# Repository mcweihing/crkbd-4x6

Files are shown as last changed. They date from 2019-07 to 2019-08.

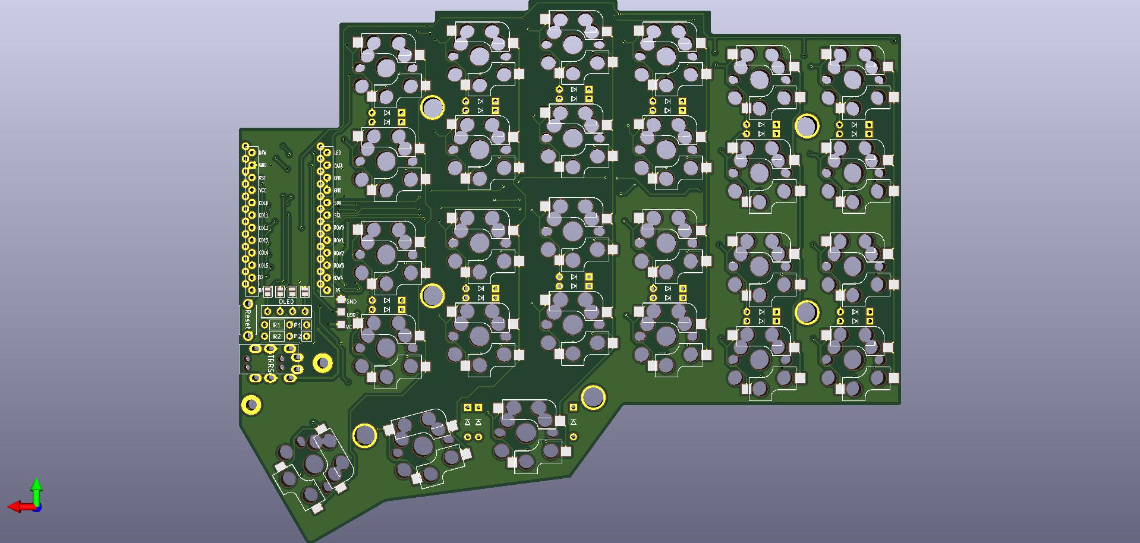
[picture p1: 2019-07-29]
pictures/back.jpg

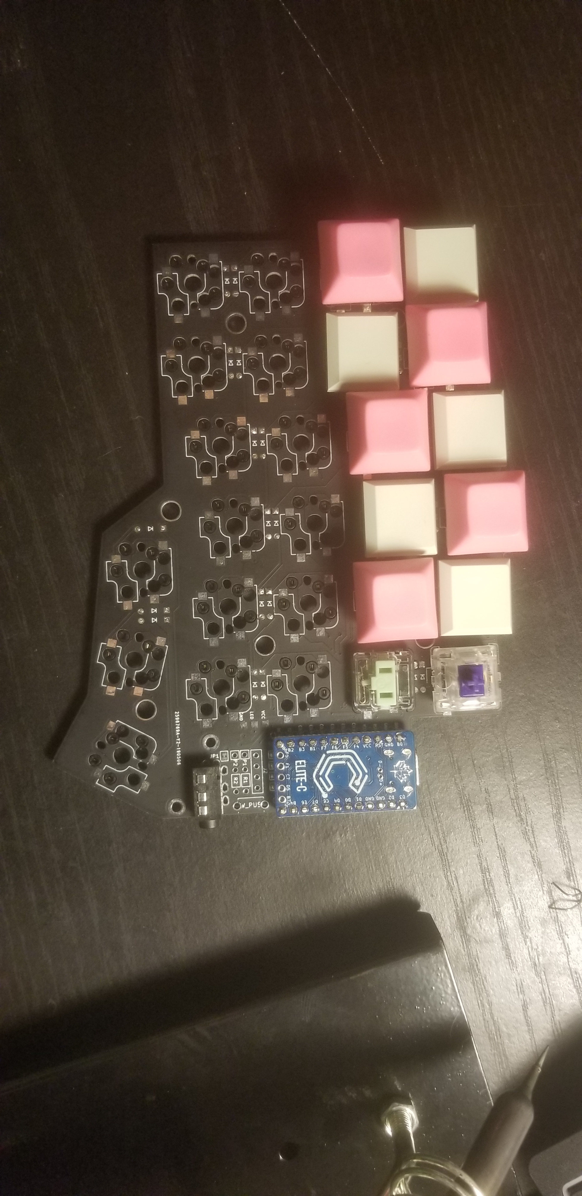
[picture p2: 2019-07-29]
pictures/20190529_184307.jpg

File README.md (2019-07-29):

An adaptation of the crkbd keyboard. It contains a 4x6 matrix and three thumb keys. It's also MX and Choc hotswappable.

All of the KiCad files needed to print the pcb are included. I know that the gerber files included are enough to print through JLCPCB.

I have dxf files to get plates made for the pcb's, but I won't have access to that computer for at least a week or two. Same with QMK.

If you want to do QMK yourself before I add it, I'll try to give the steps as best as I remember them.
There's a file which specifies rows and columns. Here, change it from 8 to 10. There's also a file which specifies input and output pins. There should be a list for rows which has D4, C6, D7, and E6. Add B4 to this. Now, you can add an extra row in the key layout and compile.

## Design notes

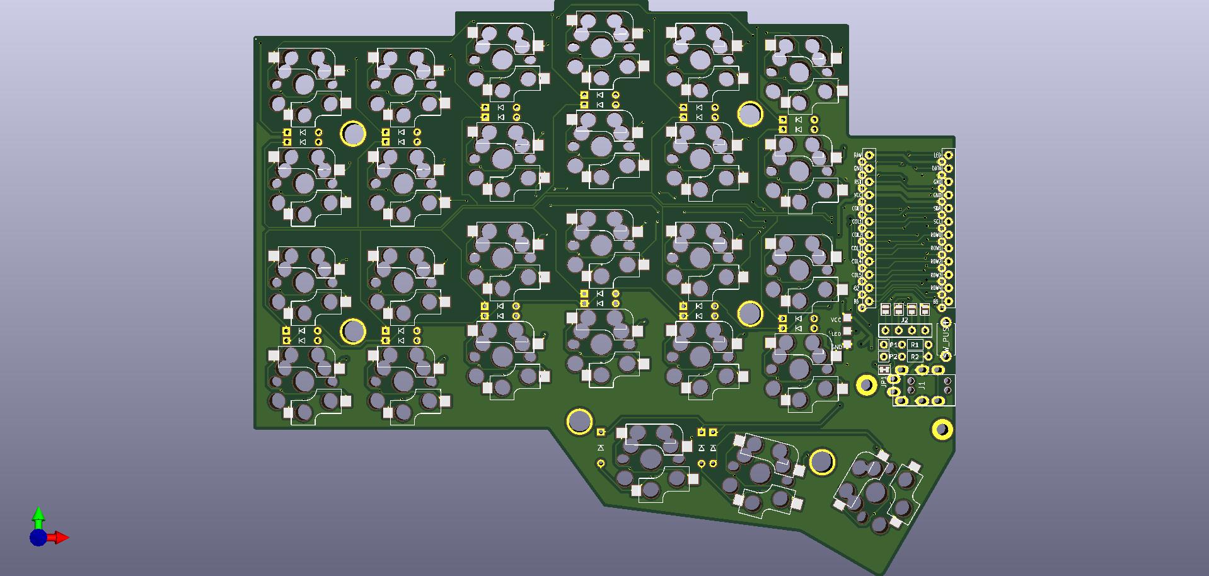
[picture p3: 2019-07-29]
pictures/front.jpg

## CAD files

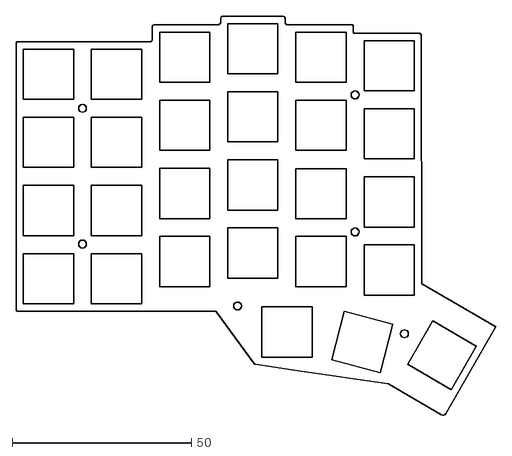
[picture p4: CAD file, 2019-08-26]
plates/frontplateMX.dxf
133.8 x 111.3

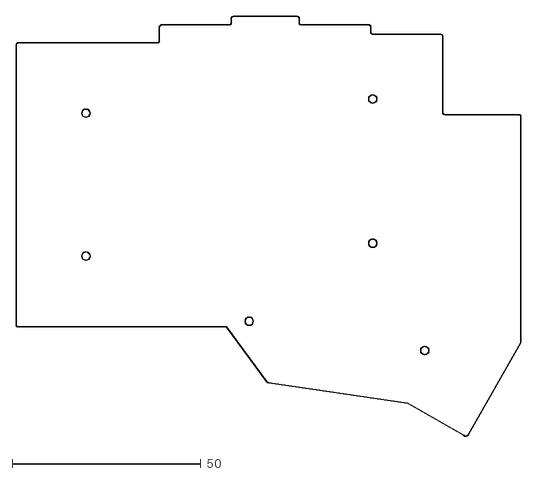
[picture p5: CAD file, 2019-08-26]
plates/backplate.dxf
133.8 x 111.3

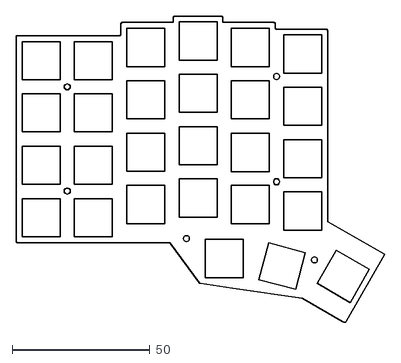
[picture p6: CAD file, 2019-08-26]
plates/frontplateChoc.dxf
133.8 x 111.3

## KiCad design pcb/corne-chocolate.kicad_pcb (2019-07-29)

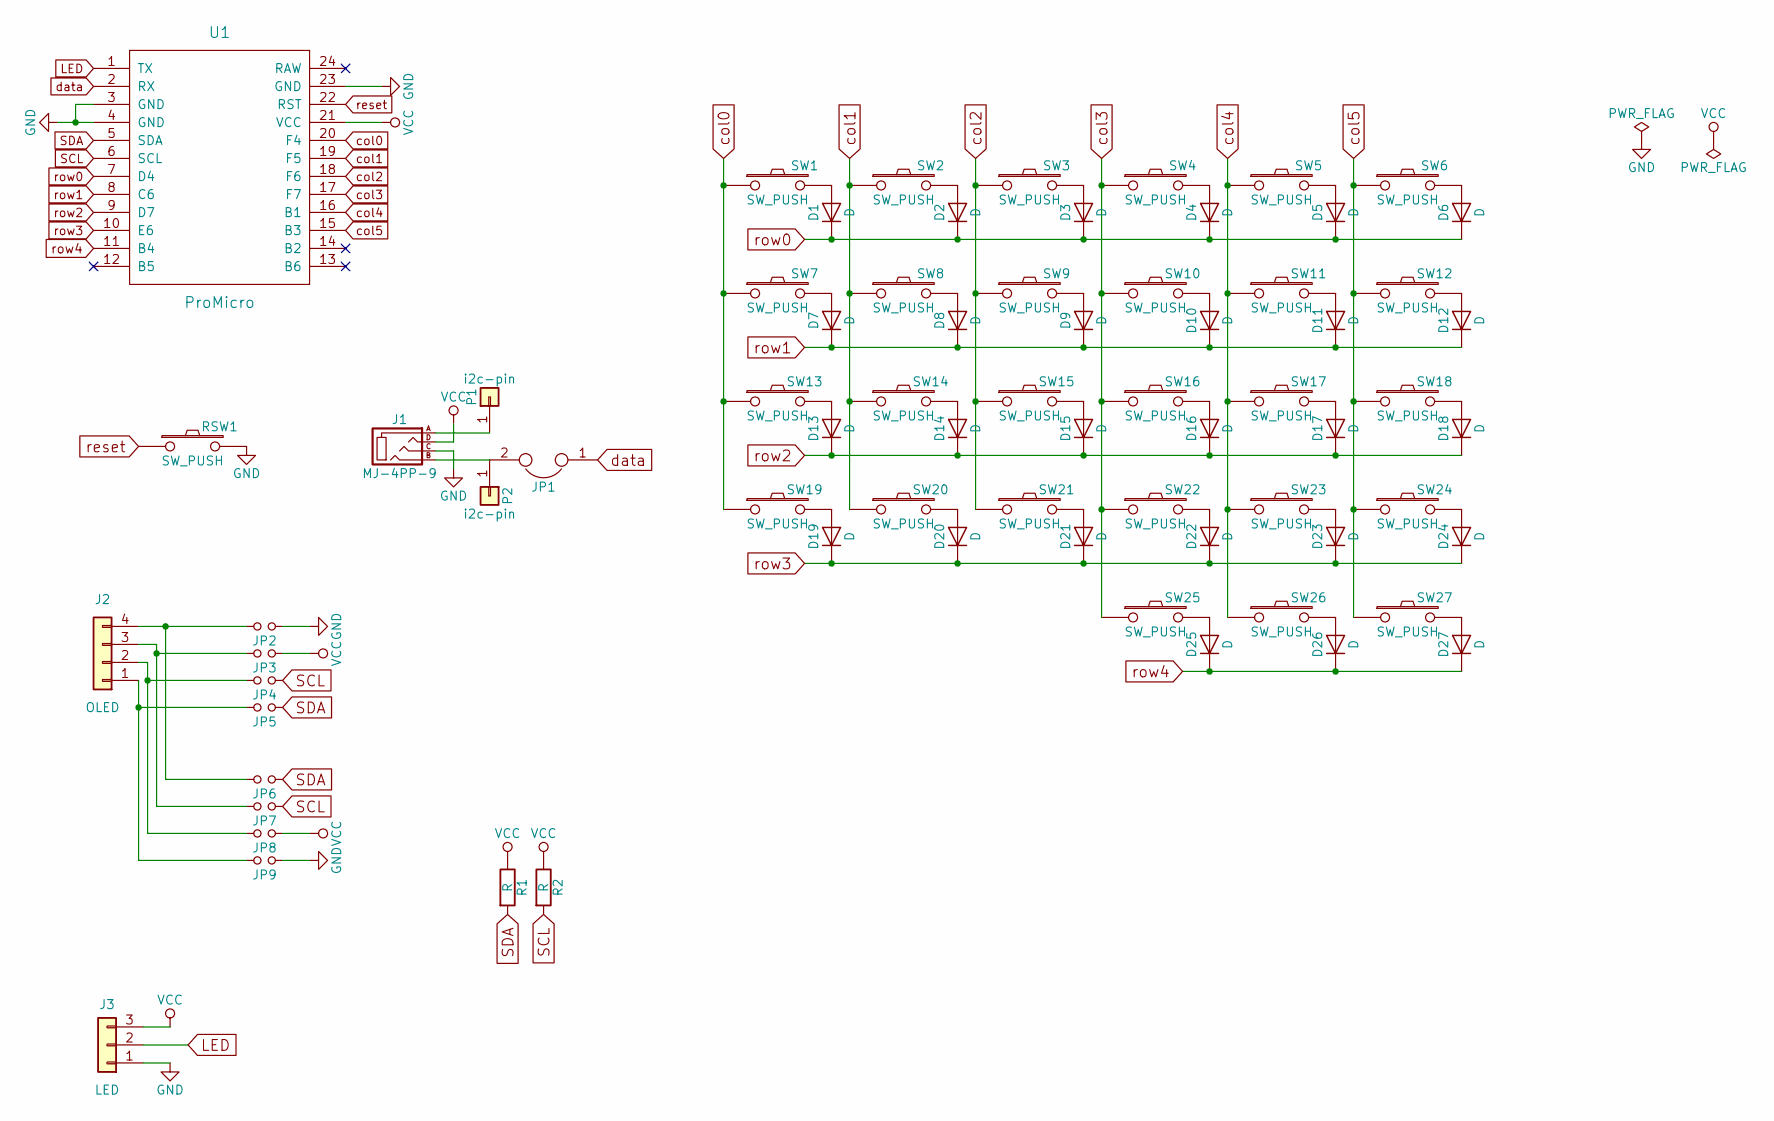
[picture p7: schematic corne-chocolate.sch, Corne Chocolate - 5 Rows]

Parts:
D1, D2, D3, D4, D5, D6, D7, D8, D9, D10, D11, D12, D13, D14, D15, D16, D17, D18, D19, D20, D21, D22, D23, D24, D25, D26, D27: D; D3_TH
J1: MJ-4PP-9
J2: OLED
J3: LED; StripLED_rev
JP1: JPC2
JP2, JP3, JP4, JP5, JP6, JP7, JP8, JP9: Jumper
P1, P2: i2c-pin; 1pin_conn
R1, R2: R
RSW1: SW_PUSH; ResetSW
SW1, SW2, SW3, SW4, SW5, SW6, SW7, SW8, SW9, SW10, SW11, SW12, SW13, SW14, SW15, SW16, SW17, SW18, SW19, SW20, SW21, SW22, SW23, SW24, SW25, SW26: SW_PUSH; CherryMX_Choc_Hotswap
SW27: SW_PUSH; CherryMX_Choc_Hotswap_1.5u
U1: ProMicro; ProMicro_v2

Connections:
GND: J1.C, J3.1, JP2.1, JP9.1, RSW1.2, U1.3 (GND), U1.4 (GND), U1.23 (GND)
LED: J3.2, U1.1 (TX)
unnamed: D1.2 (A), SW1.2
unnamed: D2.2 (A), SW2.2
unnamed: D3.2 (A), SW3.2
unnamed: D4.2 (A), SW4.2
unnamed: D5.2 (A), SW5.2
unnamed: D6.2 (A), SW6.2
unnamed: D7.2 (A), SW7.2
unnamed: D8.2 (A), SW8.2
unnamed: D9.2 (A), SW9.2
unnamed: D10.2 (A), SW10.2
unnamed: D11.2 (A), SW11.2
unnamed: D12.2 (A), SW12.2
unnamed: D13.2 (A), SW13.2
unnamed: D14.2 (A), SW14.2
unnamed: D15.2 (A), SW15.2
unnamed: D16.2 (A), SW16.2
unnamed: D17.2 (A), SW17.2
unnamed: D18.2 (A), SW18.2
unnamed: D19.2 (A), SW19.2
unnamed: D20.2 (A), SW20.2
unnamed: D21.2 (A), SW21.2
unnamed: D22.2 (A), SW22.2
unnamed: D23.2 (A), SW23.2
unnamed: D24.2 (A), SW24.2
unnamed: D25.2 (A), SW25.2
unnamed: D26.2 (A), SW26.2
unnamed: D27.2 (A), SW27.2
unnamed: J1.A, P1.1
unnamed: J1.B, JP1.2, P2.1
unnamed: J2.1, JP5.2, JP9.2
unnamed: J2.2, JP4.2, JP8.2
unnamed: J2.3, JP3.2, JP7.2
unnamed: J2.4, JP2.2, JP6.2
SCL: JP4.1, JP7.1, R2.2, U1.6 (SCL)
SDA: JP5.1, JP6.1, R1.2, U1.5 (SDA)
VCC: J1.D, J3.3, JP3.1, JP8.1, R1.1, R2.1, U1.21 (VCC)
col0: SW1.1, SW7.1, SW13.1, SW19.1, U1.20 (F4)
col1: SW2.1, SW8.1, SW14.1, SW20.1, U1.19 (F5)
col2: SW3.1, SW9.1, SW15.1, SW21.1, U1.18 (F6)
col3: SW4.1, SW10.1, SW16.1, SW22.1, SW25.1, U1.17 (F7)
col4: SW5.1, SW11.1, SW17.1, SW23.1, SW26.1, U1.16 (B1)
col5: SW6.1, SW12.1, SW18.1, SW24.1, SW27.1, U1.15 (B3)
data: JP1.1, U1.2 (RX)
reset: RSW1.1, U1.22 (RST)
row0: D1.1 (K), D2.1 (K), D3.1 (K), D4.1 (K), D5.1 (K), D6.1 (K), U1.7 (D4)
row1: D7.1 (K), D8.1 (K), D9.1 (K), D10.1 (K), D11.1 (K), D12.1 (K), U1.8 (C6)
row2: D13.1 (K), D14.1 (K), D15.1 (K), D16.1 (K), D17.1 (K), D18.1 (K), U1.9 (D7)
row3: D19.1 (K), D20.1 (K), D21.1 (K), D22.1 (K), D23.1 (K), D24.1 (K), U1.10 (E6)
row4: D25.1 (K), D26.1 (K), D27.1 (K), U1.11 (B4)

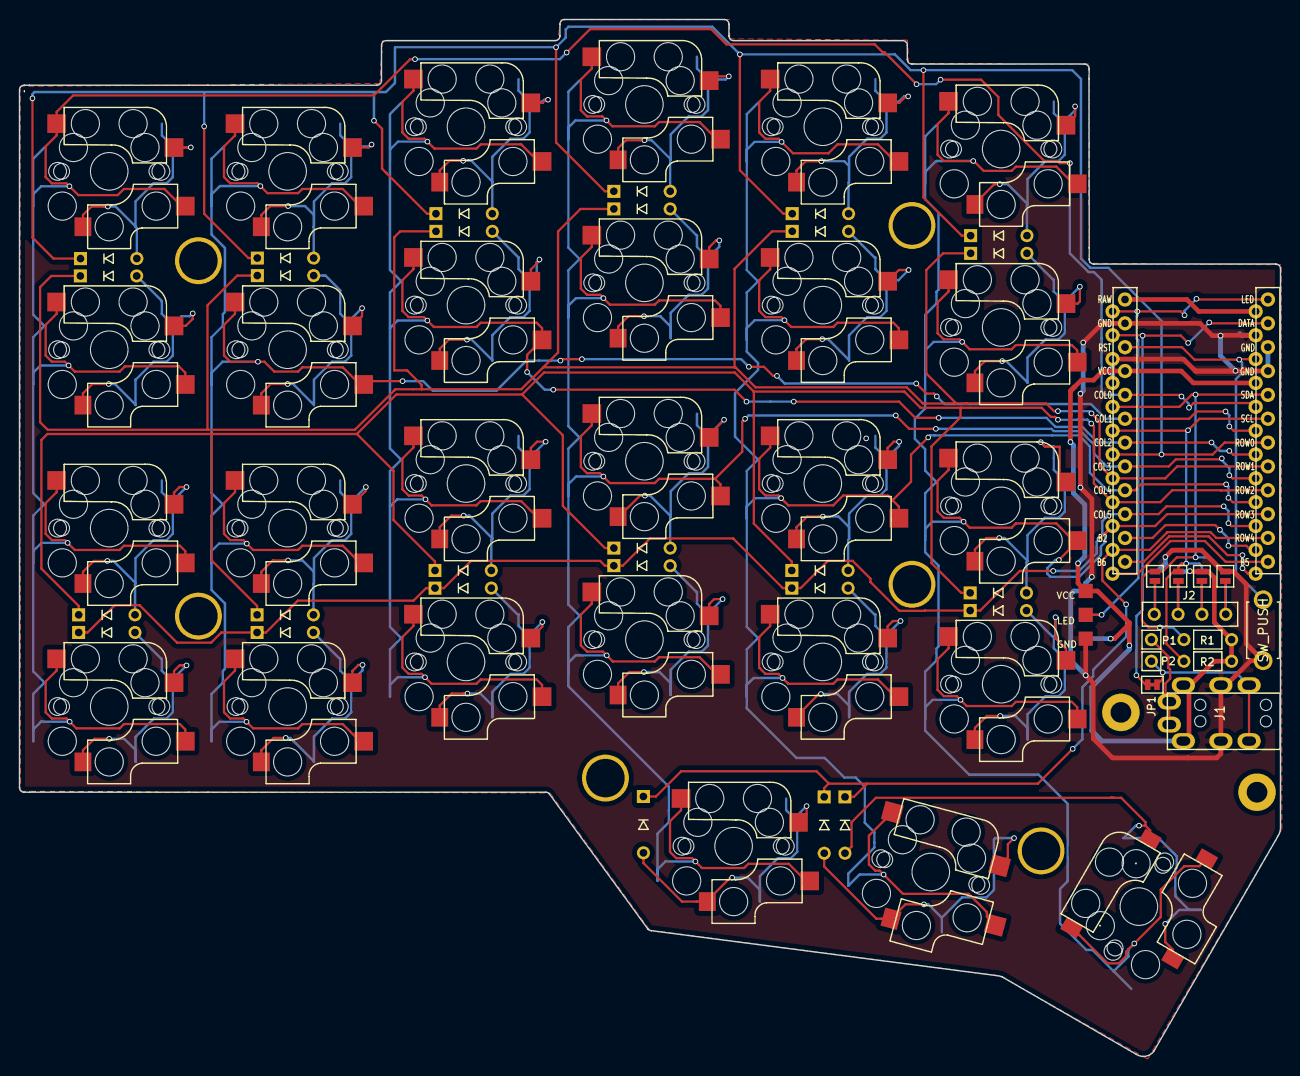
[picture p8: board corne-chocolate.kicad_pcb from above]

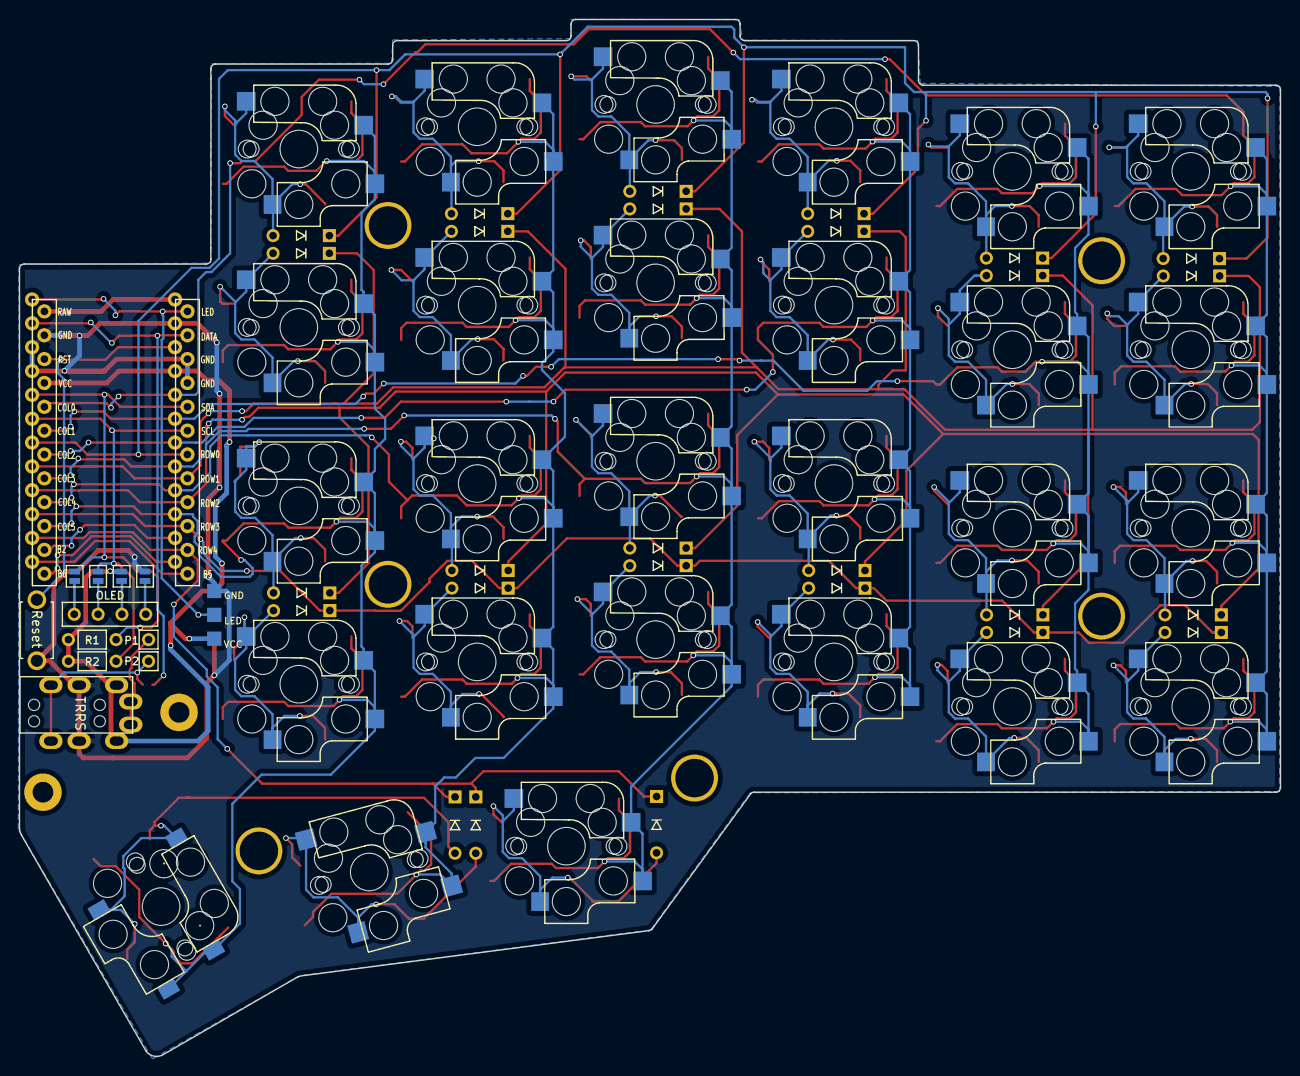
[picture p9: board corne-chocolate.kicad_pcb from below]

Board: 2 copper layers, 134.3 x 110.4 mm, 72 parts (4 on the bottom side), 51 nets.

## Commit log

2019-07-29 Added pcb files.
    [corne-chocolate-B_Cu.gbl, corne-chocolate-B_Mask.gbs, corne-chocolate-B_SilkS.gbo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]
2019-08-26 added .dxf plate files
    [backplate.dxf, frontplateChoc.dxf, frontplateMX.dxf]
2019-08-26 Switch cutout footprints for MX and Choc
